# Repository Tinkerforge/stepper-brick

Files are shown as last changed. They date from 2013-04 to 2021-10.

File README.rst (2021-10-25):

Stepper Brick
=============

This repository contains the firmware source code and the hardware design
files. The documentation generator configs can be found at
https://github.com/Tinkerforge/generators

Repository Content
------------------

software/:
 * examples/: Examples for all supported languages
 * build/: Compiled files
 * src/: Source code of firmware
 * Makefile: Makefile to build project

hardware/:
 * Contains KiCad project files and additionally schematics as PDF

datasheets/:
 * Contains datasheets for sensors and complex ICs that are used

Hardware
--------

The hardware is designed with the open source EDA Suite KiCad
(http://www.kicad.org). Before you are able to open the files,
you have to install the Tinkerforge kicad-libraries
(https://github.com/Tinkerforge/kicad-libraries). You can either clone
them directly in hardware/ or clone them in a separate folder and
symlink them into hardware/
(ln -s kicad_path/kicad-libraries project_path/hardware). After that you
can open the .pro file in hardware/ with KiCad and from there view and
modify the schematics and the PCB layout.

Software
--------

If you want to do your own Brick/Bricklet firmware development we highly
recommend that you use our build environment setup script and read the
tutorial (https://www.tinkerforge.com/en/doc/Tutorials/Tutorial_Build_Environment/Tutorial.html).

To compile the C code we recommend you to install the newest GNU Arm Embedded
Toolchain (https://launchpad.net/gcc-arm-embedded/+download).
You also need to install bricklib (https://github.com/Tinkerforge/bricklib).

You can either clone it directly in software/src/ or clone it in a
separate folder and symlink it into software/src/
(ln -s bricklib_path/bricklib project_path/software/src/). Finally make sure to
have CMake installed (http://www.cmake.org/cmake/resources/software.html).

After that you can build the firmware by invoking make in software/.
The firmware (.bin) can then be found in software/build/ and uploaded
with brickv (click button "Flashing" on start screen).

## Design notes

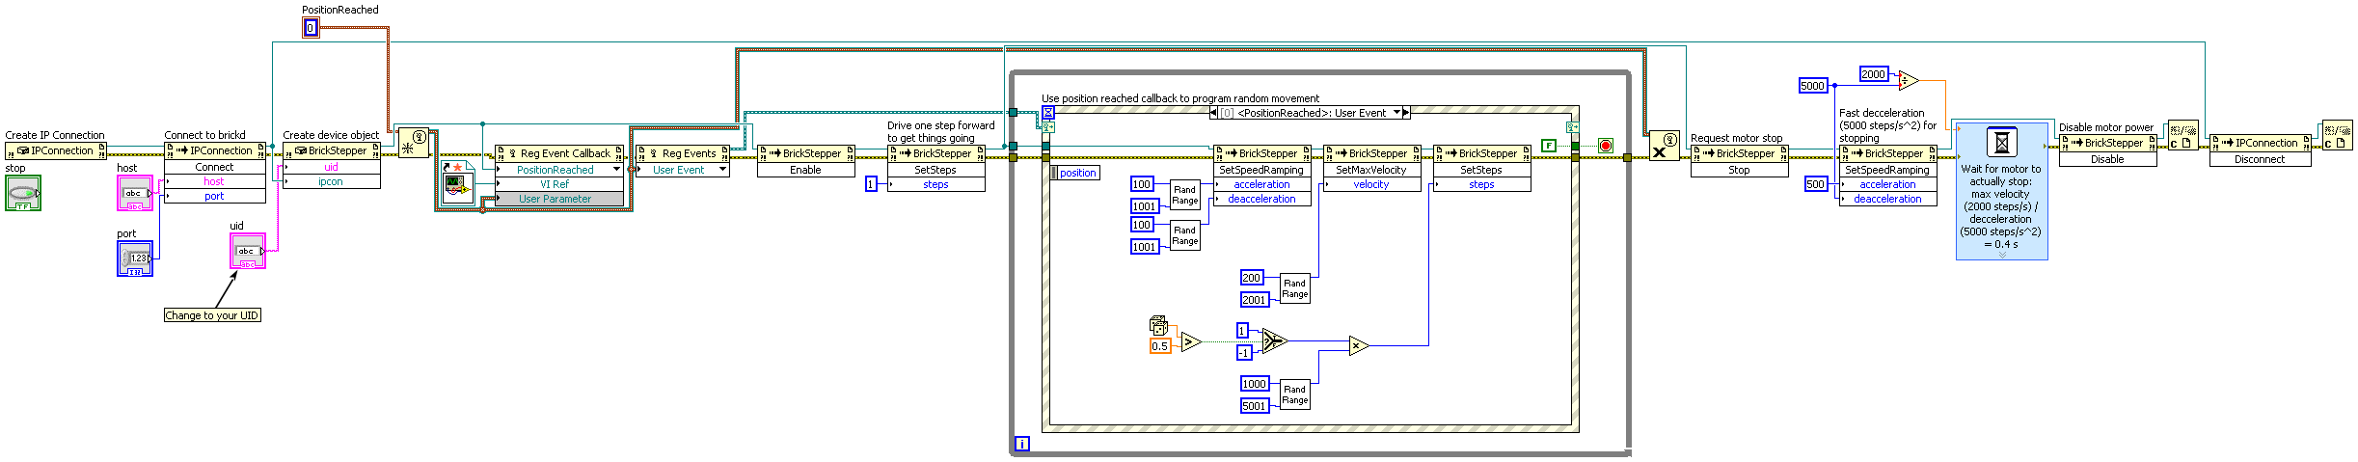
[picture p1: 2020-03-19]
software/examples/labview/Example Callback.vi.png

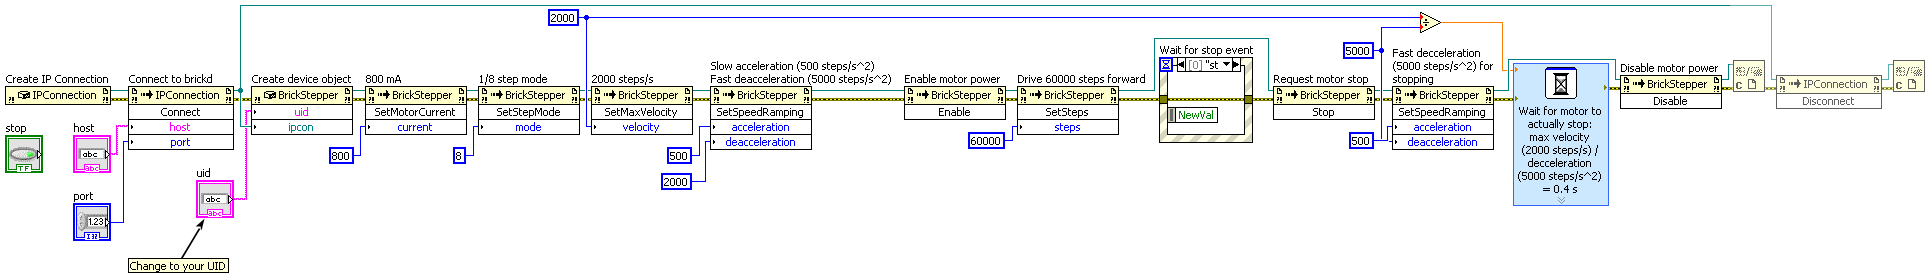
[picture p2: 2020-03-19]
software/examples/labview/Example Configuration.vi.png

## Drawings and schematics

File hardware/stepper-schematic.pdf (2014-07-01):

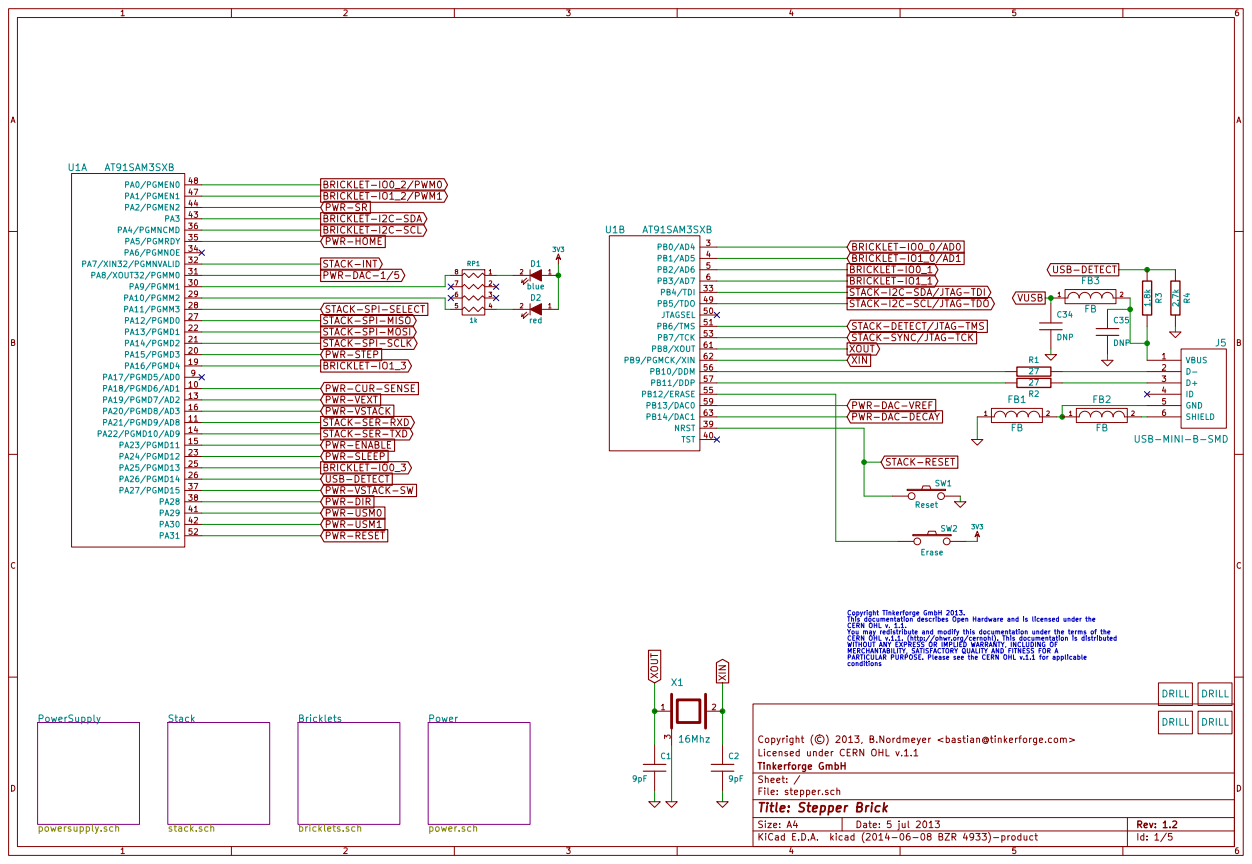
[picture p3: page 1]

BRICKLET-IO0_2/PWM0 Bricklets bricklets.sch
BRICKLET-IO1_2/PWM1
PWR-SR
BRICKLET-I2C-SDA
BRICKLET-I2C-SCL
1k PWR-HOME
3V3 BRICKLET-IO1_3
STACK-INT
conditions PWR-DAC-1/5
STACK-SER-RXD
STACK-SER-TXD
PWR-ENABLE
PWR-SLEEP
BRICKLET-IO0_3
PWR-VSTACK-SW
PWR-USM0 PWR-DIR

BRICKLET-IO0_0/AD0
BRICKLET-IO1_0/AD1
BRICKLET-IO0_1
BRICKLET-IO1_1
STACK-I2C-SDA/JTAG-TDI
STACK-I2C-SCL/JTAG-TDO

STACK-DETECT/JTAG-TMS
STACK-SYNC/JTAG-TCK
XOUT
XIN

Copyright Tinkerforge GmbH 2013. This documentation describes Open Hardware and is licensed under the CERN OHL v. 1.1. You may redistribute and modify this documentation under the terms of the CERN OHL v.1.1. (http://ohwr.org/cernohl). This documentation is distributed WITHOUT ANY EXPRESS OR IMPLIED WARRANTY, INCLUDING OF MERCHANTABILITY, SATISFACTORY QUALITY AND FITNESS FOR A

PARTICULAR PURPOSE. Please see the CERN OHL v.1.1 for applicable

Licensed under CERN OHL v.1.1 Copyright (©) 2013, B.Nordmeyer <bastian@tinkerforge.com>

File: stepper.sch Sheet: / Tinkerforge GmbH

Id: 1/5 Title: Stepper Brick

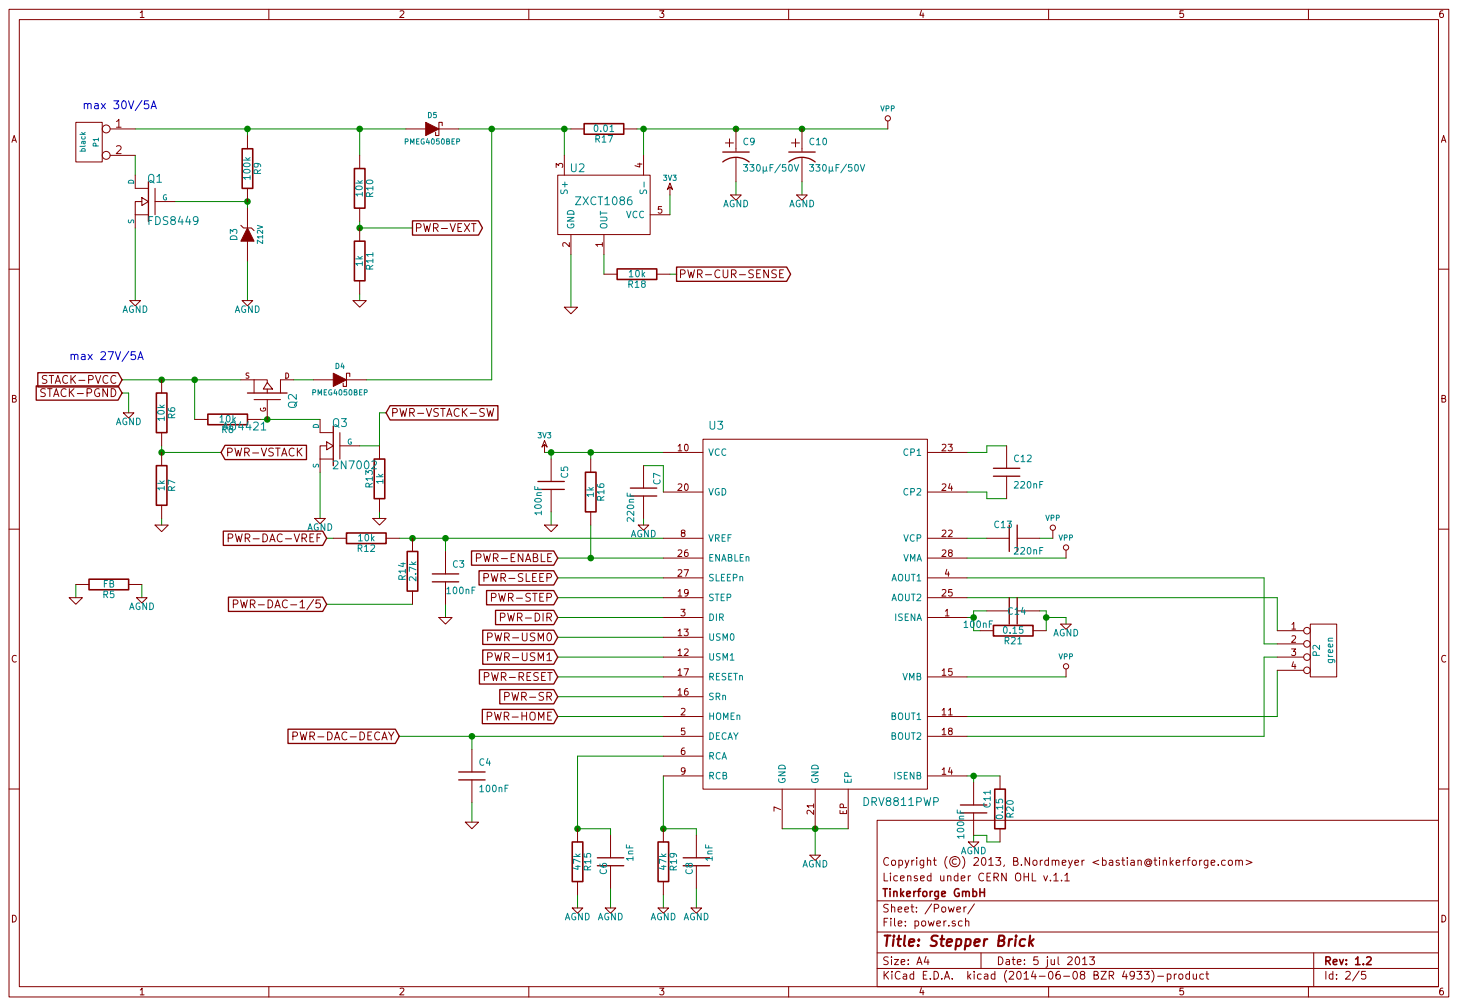
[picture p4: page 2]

7 VREF 8 RCB 9 VCC 10 VGD 20 BOUT1 11 GND 21 USM1 12 VCP 22 USM0 13 CP1 23

Licensed under CERN OHL v.1.1 Copyright (©) 2013, B.Nordmeyer <bastian@tinkerforge.com>

File: power.sch Sheet: /Power/ Tinkerforge GmbH

Id: 2/5 Title: Stepper Brick

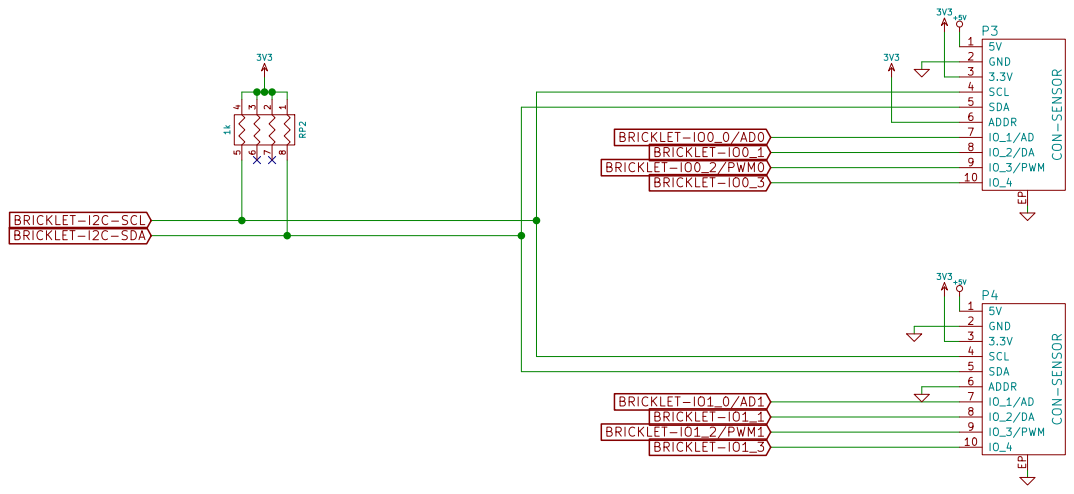
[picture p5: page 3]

File: bricklets.sch Sheet: /Bricklets/ Tinkerforge GmbH

Id: 3/5 Title: Stepper Brick

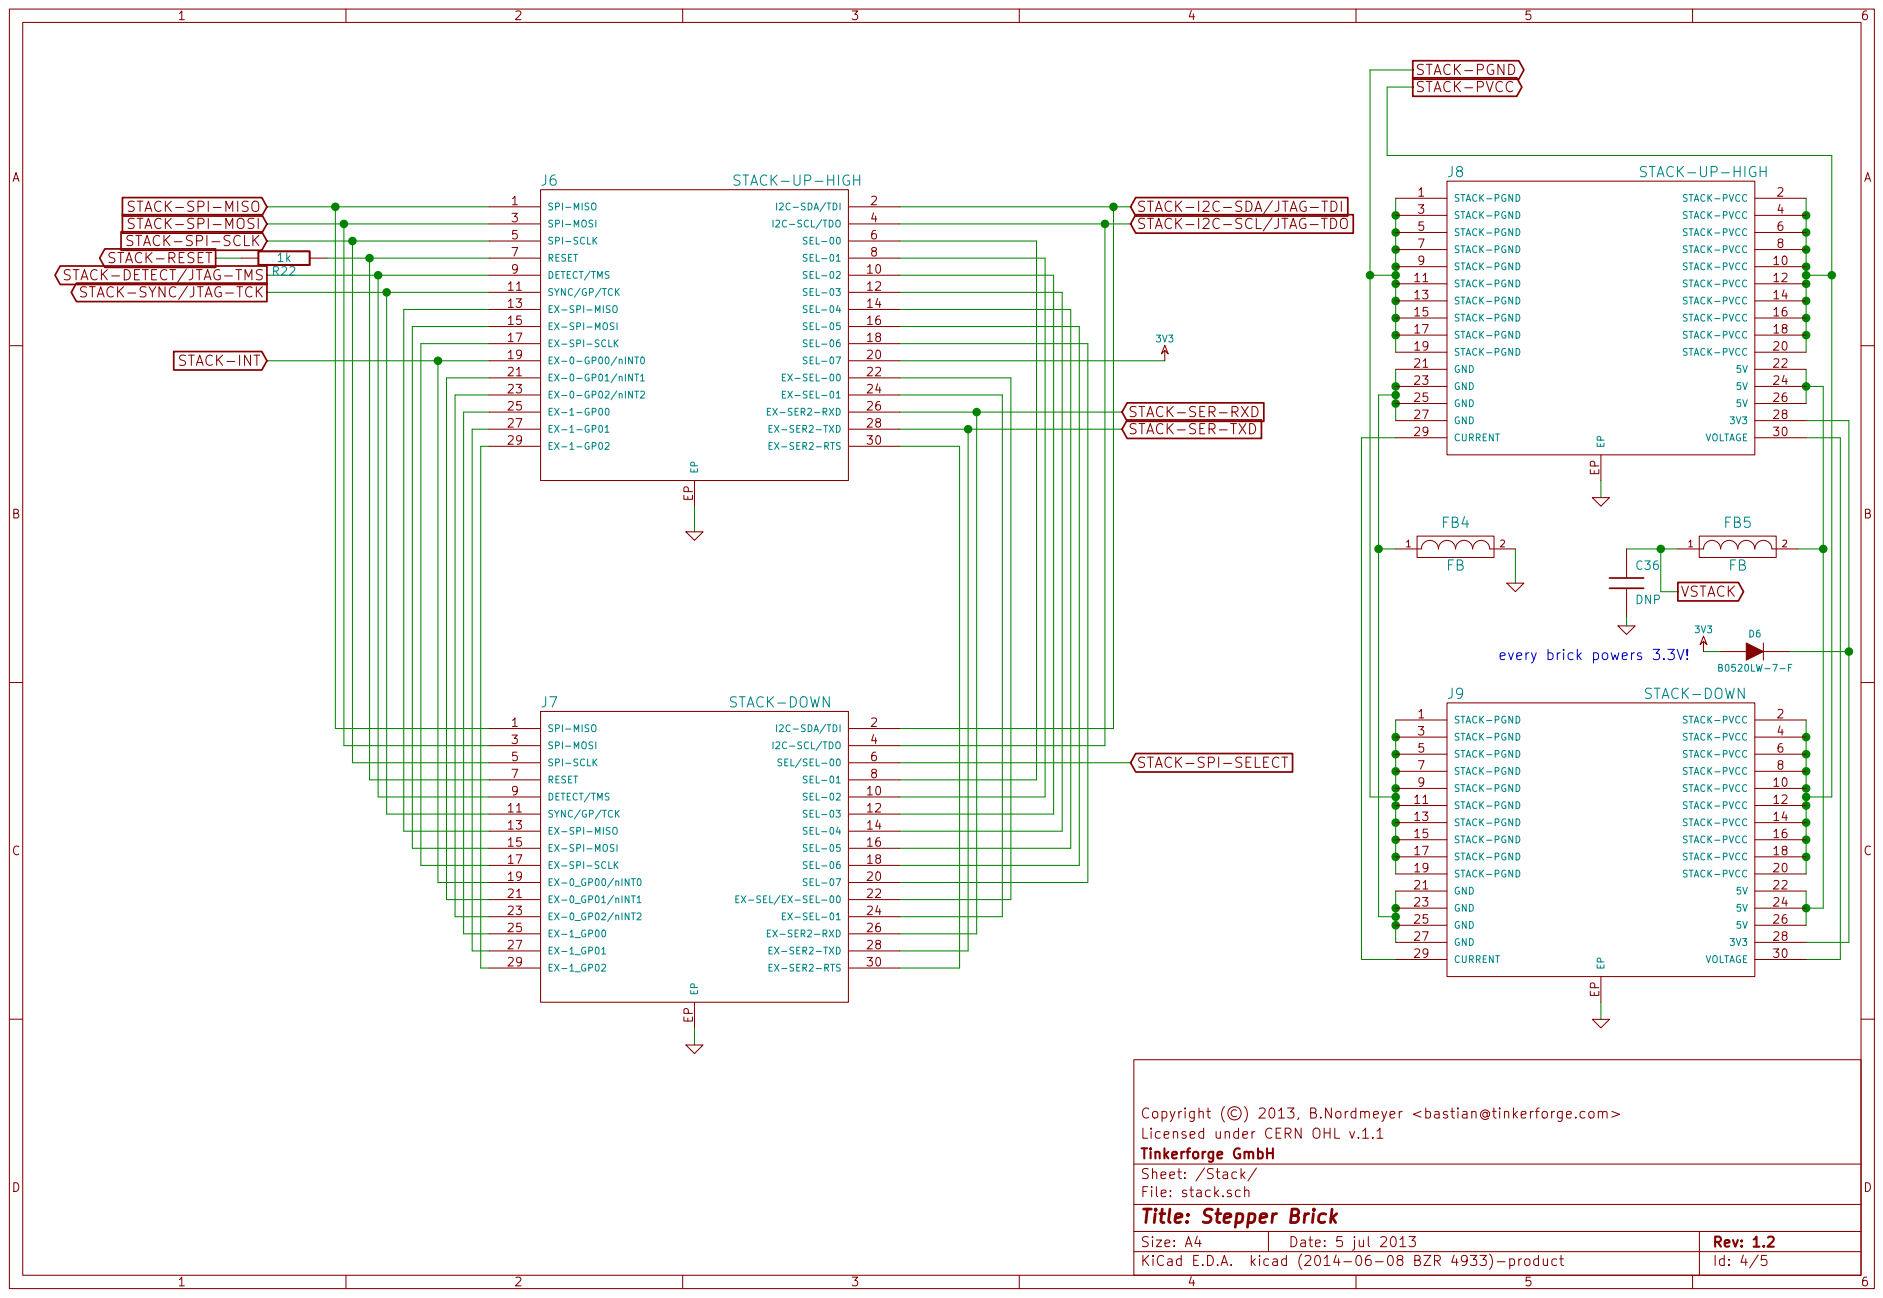
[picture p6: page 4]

STACK-SPI-MISO
STACK-SPI-MOSI
STACK-SPI-SCLK
STACK-RESET
STACK-DETECT/JTAG-TMS
STACK-SYNC/JTAG-TCK

STACK-I2C-SDA/JTAG-TDI
STACK-I2C-SCL/JTAG-TDO

Licensed under CERN OHL v.1.1 Copyright (©) 2013, B.Nordmeyer <bastian@tinkerforge.com>

File: stack.sch Sheet: /Stack/ Tinkerforge GmbH

Id: 4/5 Title: Stepper Brick

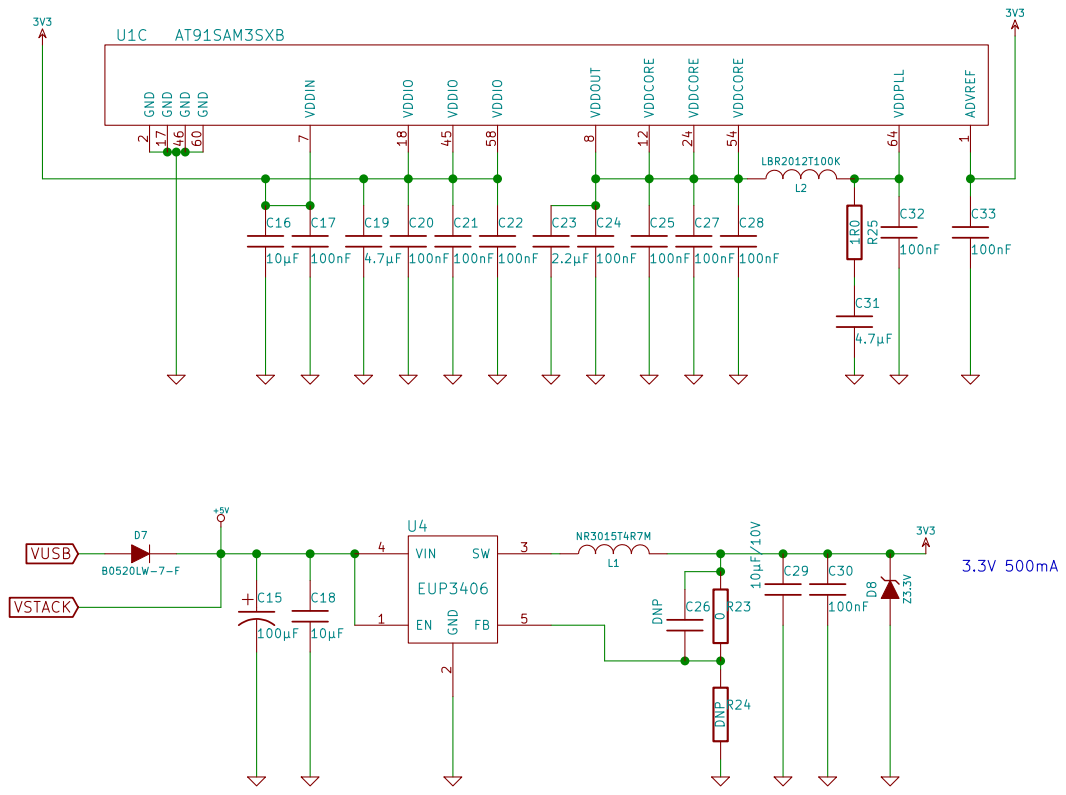
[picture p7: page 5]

8 GND 60 VDDCORE 12 VDDCORE 24 VDDCORE 54 VDDPLL 64 VDDIO 45 GND 46 GND 17 VDDIO 18 VDDIO 58

Licensed under CERN OHL v.1.1 Copyright (©) 2013, B.Nordmeyer <bastian@tinkerforge.com>

Tinkerforge GmbH
Sheet: /PowerSupply/
File: powersupply.sch
Id: 5/5 Title: Stepper Brick

D Date: 5 jul 2013

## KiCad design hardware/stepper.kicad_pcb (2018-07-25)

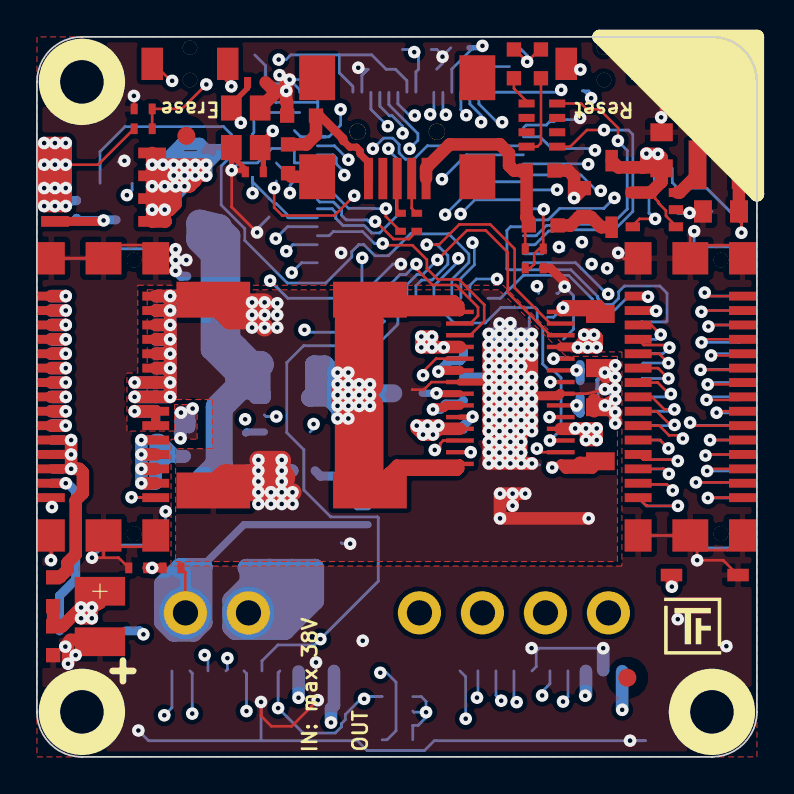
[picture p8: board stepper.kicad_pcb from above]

Board: 4 copper layers, 40.0 x 40.0 mm, 107 parts (0 on the bottom side), 109 nets.

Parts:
C1, C2: 9pF; C0402
C3, C4, C5, C11, C14, C17, C20, C21, C22, C24, C25, C27, C28, C30, C32, C33: 100nF; C0402
C6, C8: 1nF; C0402
C7, C12, C13: 220nF; C0603
C9, C10: 330µF/50V; ELKO_103
C15: 100µF; 3528-21
C16, C18: 10µF; C0805
C19, C31: 4.7µF; C0603
C23: 2.2µF; C0603
C26: DNP; C0402
C29: 10µF/10V; C0805
C34, C35, C36: DNP; C0603
D1: blue; D0603
D2: red; D0603
D3: Z12V; SOD-123
D4, D5: PMEG4050BEP; SOD-128
D6, D7: B0520LW-7-F; SOD-123
D8: Z3.3V; SOD-123
FB1, FB2, FB3, FB4, FB5: FB; C0603
Fiducial_Mark: VAL**; Fiducial_Mark
Fiducial_Mark#2, Fiducial_Mark#3, Fiducial_Mark#4: VAL**; Fiducial_Mark
J1, J2, J3, J4: DRILL; DRILL_NP
J5: USB-MINI-B-SMD
J6, J8: STACK-UP-HIGH; BTB08-ACS-TOP
J7, J9: STACK-DOWN; BTB08-ACS-BTM
L1: NR3015T4R7M; NR3030
L2: LBR2012T100K; C0805
P1: black; OQ_2P
P2: green; OQ_4P
P3, P4: CON-SENSOR
Q1: FDS8449; SOIC-8-MOSFET
Q2: AO4421; SOIC-8-MOSFET
Q3: 2N7002; SOT23GDS
R1, R2: 27; R0402
R3: 1.8k; R0402
R4, R14: 2.7k; R0402
R5: FB; C0603
R6, R10, R12, R18: 10k; R0402
R7, R11, R13, R16, R22: 1k; R0402
R8: 10k; 0402
R9: 100k; R0402
R15, R19: 47k; R0402
R17: 0.01; R1206
R20, R21: 0.15; R1206
R23: 0; R0603
R24: DNP; R0603
R25: 1R0; R0402
RP1, RP2: 1k; 4X0603
SW1: Reset; TACT-SWITCH
SW2: Erase; TACT-SWITCH
U1: AT91SAM3SXB; LQFP64
U2: ZXCT1086; SOT23-5
U3: DRV8811PWP; HTSSOP28
U4: EUP3406; SOT23-5
VAL: WEEE_7mm
VAL#2: CE_5mm
X1: 16Mhz; CRYSTAL_3225

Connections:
3V3: C5.2, C16.1, C17.1, C19.1, C20.1, C21.1, C22.1, C26.1, C29.1, C30.1, C33.1, D1.1, D2.1, D6.1, D8.2, J6.20, L1.2, P3.3, P3.6, P4.3, R16.1, R23.1, RP2.1, RP2.2, RP2.3, RP2.4, SW2.2, U1.1, U1.7, U1.18, U1.45, U1.58, U2.5, U3.10
BRICKLET-I2C-SCL: P3.4, P4.4, RP2.5, U1.36
BRICKLET-I2C-SDA: P3.5, P4.5, RP2.8, U1.43
BRICKLET-IO0_0/AD0: P3.7, U1.3
BRICKLET-IO0_1: P3.8, U1.5
BRICKLET-IO0_2/PWM0: P3.9, U1.48
BRICKLET-IO0_3: P3.10, U1.25
BRICKLET-IO1_0/AD1: P4.7, U1.4
BRICKLET-IO1_1: P4.8, U1.6
BRICKLET-IO1_2/PWM1: P4.9, U1.47
BRICKLET-IO1_3: P4.10, U1.19
GND: C1.2, C2.2, C3.2, C4.2, C5.1, C15.2, C16.2, C17.2, C18.2, C19.2, C20.2, C21.2, C22.2, C23.2, C24.2, C25.2, C27.2, C28.2, C29.2, C30.2, C31.2, C32.2, C33.2, C34.2, C35.2, C36.2, D8.1, FB1.1, FB4.2, J6.EP, J7.EP, J8.EP, J9.EP, P3.2, P3.EP, P4.2, P4.6, P4.EP, R4.1, R5.2, R7.2, R11.2, R13.1, R24.2, SW1.2, U1.2, U1.17, U1.46, U1.60, U2.2, U4.2, X1.3
unnamed: C3.1, R12.1, R14.2, U3.8
unnamed: C6.1, R15.1, U3.6
unnamed: C7.2, U3.20
unnamed: C8.1, R19.1, U3.9
unnamed: C11.2, R20.1, U3.14
unnamed: C12.1, U3.23
unnamed: C12.2, U3.24
unnamed: C13.2, U3.22
unnamed: C14.1, R21.2, U3.1
unnamed: C23.1, C24.1, C25.1, C27.1, C28.1, L2.1, U1.8, U1.12, U1.24, U1.54
unnamed: C26.2, R23.2, R24.1, U4.5
unnamed: C31.1, R25.1
unnamed: C32.1, L2.2, R25.2, U1.64
unnamed: C35.1, FB3.2, J5.1, R3.1
unnamed: D1.2, RP1.1
unnamed: D2.2, RP1.4
unnamed: D3.2, Q1.G, R9.2
unnamed: D4.1, Q2.D
unnamed: D4.2, D5.2, R17.2, U2.3
unnamed: D5.1, P1.1, R9.1, R10.1
unnamed: D6.2, J8.28, J9.28
unnamed: FB1.2, FB2.1, J5.5
unnamed: FB2.2, J5.6
unnamed: FB4.1, J8.21, J8.23, J8.25, J8.27, J9.21, J9.23, J9.25, J9.27
unnamed: FB5.2, J8.22, J8.24, J8.26, J9.22, J9.24, J9.26
unnamed: J5.2, R1.1
unnamed: J5.3, R2.1
unnamed: J6.6, J7.8
unnamed: J6.7, J7.7, R22.1
unnamed: J6.8, J7.10
unnamed: J6.10, J7.12
unnamed: J6.12, J7.14
unnamed: J6.13, J7.13
unnamed: J6.14, J7.16
unnamed: J6.15, J7.15
unnamed: J6.16, J7.18
unnamed: J6.17, J7.17
unnamed: J6.18, J7.20
unnamed: J6.21, J7.21
unnamed: J6.22, J7.22
unnamed: J6.23, J7.23
unnamed: J6.24, J7.24
unnamed: J6.25, J7.25
unnamed: J6.27, J7.27
unnamed: J6.29, J7.29
unnamed: J6.30, J7.30
unnamed: J8.29, J9.29
unnamed: J8.30, J9.30
unnamed: L1.1, U4.3
unnamed: P1.2, Q1.D
unnamed: P2.1, U3.25
unnamed: P2.2, U3.4
unnamed: P2.3, U3.18
unnamed: P2.4, U3.11
unnamed: Q2.G, Q3.D, R8.1
unnamed: R1.2, U1.56
unnamed: R2.2, U1.57
unnamed: R18.2, U2.1
unnamed: RP1.5, U1.29
unnamed: RP1.8, U1.30
unnamed: SW2.1, U1.55
PWR-CUR-SENSE: R18.1, U1.10
PWR-DAC-1/5: R14.1, U1.31
PWR-DAC-DECAY: C4.1, U1.63, U3.5
PWR-DAC-VREF: R12.2, U1.59
PWR-DIR: U1.38, U3.3
PWR-ENABLE: R16.2, U1.15, U3.26
PWR-HOME: U1.35, U3.2
PWR-RESET: U1.52, U3.17
PWR-SLEEP: U1.23, U3.27
PWR-SR: U1.44, U3.16
PWR-STEP: U1.20, U3.19
PWR-USM0: U1.41, U3.13
PWR-USM1: U1.42, U3.12
PWR-VEXT: R10.2, R11.1, U1.13
PWR-VSTACK: R6.2, R7.1, U1.16
PWR-VSTACK-SW: Q3.G, R13.2, U1.37
STACK-DETECT/JTAG-TMS: J6.9, J7.9, U1.51
STACK-I2C-SCL/JTAG-TDO: J6.4, J7.4, U1.49
STACK-I2C-SDA/JTAG-TDI: J6.2, J7.2, U1.33
STACK-INT: J6.19, J7.19, U1.32
STACK-PGND: C6.2, C7.1, C8.2, C9.2, C10.2, C11.1, C14.2, D3.1, J8.1, J8.3, J8.5, J8.7, J8.9, J8.11, J8.13, J8.15, J8.17, J8.19, J9.1, J9.3, J9.5, J9.7, J9.9, J9.11, J9.13, J9.15, J9.17, J9.19, Q1.S, Q3.S, R5.1, R15.2, R19.2, R20.2, R21.1, U3.7, U3.21, U3.EP
STACK-PVCC: J8.2, J8.4, J8.6, J8.8, J8.10, J8.12, J8.14, J8.16, J8.18, J8.20, J9.2, J9.4, J9.6, J9.8, J9.10, J9.12, J9.14, J9.16, J9.18, J9.20, Q2.S, R6.1, R8.2
STACK-RESET: R22.2, SW1.1, U1.39
STACK-SER-RXD: J6.26, J7.26, U1.11
STACK-SER-TXD: J6.28, J7.28, U1.14
STACK-SPI-MISO: J6.1, J7.1, U1.27
STACK-SPI-MOSI: J6.3, J7.3, U1.22
STACK-SPI-SCLK: J6.5, J7.5, U1.21
STACK-SPI-SELECT: J7.6, U1.28
STACK-SYNC/JTAG-TCK: J6.11, J7.11, U1.53
USB-DETECT: R3.2, R4.2, U1.26
VPP: C9.1, C10.1, C13.1, R17.1, U2.4, U3.15, U3.28
VSTACK: C15.1, C18.1, C36.1, D7.2, FB5.1, P3.1, P4.1, U4.1, U4.4
VUSB: C34.1, D7.1, FB3.1
XIN: C2.1, U1.62, X1.2
XOUT: C1.1, U1.61, X1.1

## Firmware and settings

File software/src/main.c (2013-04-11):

/* stepper-brick
 * Copyright (C) 2010-2013 Olaf Lüke <olaf@tinkerforge.com>
 *
 * main.c: Stepper Brick startup code
 *
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
 * You should have received a copy of the GNU Lesser General Public
 * License along with this library; if not, write to the
 * Free Software Foundation, Inc., 59 Temple Place - Suite 330,
 * Boston, MA 02111-1307, USA.
 */

#include <stdbool.h>
#include <stdint.h>
#include <stdio.h>
#include <stdlib.h>

#include "bricklib/free_rtos/include/FreeRTOS.h"
#include "bricklib/free_rtos/include/task.h"

#include "bricklib/com/i2c/i2c_pca9549/i2c_pca9549.h"
#include "bricklib/com/spi/spi_stack/spi_stack_master.h"
#include "bricklib/com/spi/spi_stack/spi_stack_slave.h"
#include "bricklib/com/spi/spi_stack/spi_stack_common.h"
#include "bricklib/com/i2c/i2c_eeprom/i2c_eeprom_master.h"
#include "bricklib/com/i2c/i2c_eeprom/i2c_eeprom_slave.h"
#include "bricklib/com/usb/usb.h"
#include "bricklib/logging/logging.h"
#include "bricklib/bricklet/bricklet_init.h"
#include "bricklib/drivers/uid/uid.h"
#include "bricklib/drivers/wdt/wdt.h"
#include "bricklib/drivers/pio/pio.h"
#include "bricklib/utility/init.h"
#include "bricklib/utility/profiling.h"
#include "bricklib/utility/led.h"
#include "bricklib/logging/logging.h"

#include "config.h"
#include "communication.h"
#include "stepper.h"

uint8_t brick_hardware_version[3];
extern bool usb_first_connection;

void vApplicationStackOverflowHook(xTaskHandle *pxTask, signed char *pcTaskName) {
	logf("Stack Overflow\n\r");
	while(true);
}

int main() {
	brick_hardware_version[0] = BRICK_HARDWARE_VERSION_MAJOR;
	brick_hardware_version[1] = BRICK_HARDWARE_VERSION_MINOR;
	brick_hardware_version[2] = BRICK_HARDWARE_VERSION_REVISION;

	brick_init();
	wdt_restart();

    if(usb_is_connected()) {
    	logi("Configure as USB device\n\r");
    	usb_init();
    	wdt_restart();

    	xTaskCreate(usb_message_loop,
    				(signed char *)"usb_ml",
    				1000,
    				NULL,
    				1,
    				(xTaskHandle *)NULL);
    } else {
    	logi("Configure as Stack Participant (SPI)\n\r");
    	usb_first_connection = false;
        spi_stack_slave_init();
    	wdt_restart();

    	xTaskCreate(spi_stack_slave_message_loop,
    			    (signed char *)"spi_ml",
    			    2500,
    			    NULL,
    			    1,
    			    (xTaskHandle *)NULL);
    }

	stepper_init();
    wdt_restart();

	brick_init_start_tick_task();
    wdt_restart();

	vTaskStartScheduler();
}

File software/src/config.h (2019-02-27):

/* stepper-brick
 * Copyright (C) 2010-2012 Olaf Lüke <olaf@tinkerforge.com>
 *
 * config.h: Stepper-Brick specific configuration
 *
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
 * You should have received a copy of the GNU Lesser General Public
 * License along with this library; if not, write to the
 * Free Software Foundation, Inc., 59 Temple Place - Suite 330,
 * Boston, MA 02111-1307, USA.
 */

#ifndef CONFIG_H
#define CONFIG_H

#include "communication.h"
#include "bricklib/drivers/board/sam3s/SAM3S.h"
#include "stepper.h"

#define BRICK_FIRMWARE_VERSION_MAJOR 2
#define BRICK_FIRMWARE_VERSION_MINOR 3
#define BRICK_FIRMWARE_VERSION_REVISION 10

#define BRICK_HARDWARE_VERSION_MAJOR 1
#define BRICK_HARDWARE_VERSION_MINOR 1
#define BRICK_HARDWARE_VERSION_REVISION 0

#define BRICK_DEVICE_IDENTIFIER 15

// ************** DEBUG SETTINGS **************
#define DEBUG_SPI_STACK 1
#define DEBUG_I2C_EEPROM 0
#define DEBUG_STARTUP 1
#define DEBUG_BRICKLET 1
#define DEBUG_STEPPER 1
//#define PROFILING
//#define PROFILING_TIME 100 // After how many seconds profiling is printed

#define DISABLE_JTAG_ON_STARTUP
//#define LOGGING_SERIAL
//#define LOGGING_LEVEL LOGGING_DEBUG
#define LOGGING_LEVEL LOGGING_NONE


// ************** BRICK SETTINGS **************

// Frequencies
#define BOARD_MCK      64000000 // Frequency of brick
#define BOARD_MAINOSC  16000000 // Frequency of oscillator
#define BOARD_ADC_FREQ 16000000 // Frequency of ADC
#define BOARD_OSC_EXTERNAL      // Use external oscillator

#define BRICK_HAS_CO_MCU_SUPPORT

// UART for console output (printf)
#define PIN_CONSOLE_RXD  {1 << 21, PIOA, ID_PIOA, PIO_PERIPH_A, PIO_DEFAULT}
#define PIN_CONSOLE_TXD  {1 << 22, PIOA, ID_PIOA, PIO_PERIPH_A, PIO_DEFAULT}

#define CONSOLE_BAUDRATE 115200
#define CONSOLE_USART    USART1
#define CONSOLE_ID       ID_USART1
#define CONSOLE_PINS     {PIN_CONSOLE_RXD, PIN_CONSOLE_TXD}

#define PINS_UART        {PIN_CONSOLE_RXD, PIN_CONSOLE_TXD}

// TWI
// TWI version
#define TWI_V3XX

// TWI stack definitions (for reading of eeproms from Bricks in stack)
#define TWI_STACK           TWI1
#define PIN_TWI_TWD_STACK   {1 << 4, PIOB, ID_PIOB, PIO_PERIPH_A, PIO_DEFAULT}
#define PIN_TWI_TWCK_STACK  {1 << 5, PIOB, ID_PIOB, PIO_PERIPH_A, PIO_DEFAULT}
#define PINS_TWI_STACK      PIN_TWI_TWD_STACK, PIN_TWI_TWCK_STACK

// TWI bricklet definitions (for bricklets, spi select and brick specific
//                           functions)
#define TWI_BRICKLET           TWI0
#define PIN_TWI_TWD_BRICKLET   {1 << 3, PIOA, ID_PIOA, PIO_PERIPH_A, PIO_DEFAULT}
#define PIN_TWI_TWCK_BRICKLET  {1 << 4, PIOA, ID_PIOA, PIO_PERIPH_A, PIO_DEFAULT}
#define PINS_TWI_BRICKLET      PIN_TWI_TWD_BRICKLET, PIN_TWI_TWCK_BRICKLET

// USB
// USB VBUS monitoring pin for USB plug and play
#define PIN_USB_DETECT  {1 << 26, PIOA, ID_PIOA, PIO_INPUT, PIO_DEFAULT}
// USB product descriptor (name of brick)
#define PRODUCT_DESCRIPTOR { \
	USBStringDescriptor_LENGTH(13), \
    USBGenericDescriptor_STRING, \
    USBStringDescriptor_UNICODE('S'), \
    USBStringDescriptor_UNICODE('t'), \
    USBStringDescriptor_UNICODE('e'), \
    USBStringDescriptor_UNICODE('p'), \
    USBStringDescriptor_UNICODE('p'), \
    USBStringDescriptor_UNICODE('e'), \
    USBStringDescriptor_UNICODE('r'), \
    USBStringDescriptor_UNICODE(' '), \
    USBStringDescriptor_UNICODE('B'), \
    USBStringDescriptor_UNICODE('r'), \
    USBStringDescriptor_UNICODE('i'), \
    USBStringDescriptor_UNICODE('c'), \
    USBStringDescriptor_UNICODE('k') \
}


// SPI
#define PIN_SPI_MISO        {1 << 12, PIOA, ID_PIOA, PIO_PERIPH_A, PIO_DEFAULT}
#define PIN_SPI_MOSI        {1 << 13, PIOA, ID_PIOA, PIO_PERIPH_A, PIO_DEFAULT}
#define PIN_SPI_SPCK        {1 << 14, PIOA, ID_PIOA, PIO_PERIPH_A, PIO_DEFAULT}

#define PINS_SPI            PIN_SPI_MISO, PIN_SPI_MOSI, PIN_SPI_SPCK

#define PIN_SPI_SELECT_SLAVE  {1 << 11, PIOA, ID_PIOA, PIO_PERIPH_A, PIO_DEFAULT}

// LED
#define PIN_LED_STD_BLUE    {1 << 9, PIOA, ID_PIOA, PIO_OUTPUT_1, PIO_DEFAULT}
#define PIN_LED_STD_RED     {1 << 10, PIOA, ID_PIOA, PIO_OUTPUT_1, PIO_DEFAULT}
#define PINS_STD_LED        PIN_LED_STD_BLUE, PIN_LED_STD_RED
#define PINS_LED            PINS_STD_LED

#define LED_STD_BLUE        0
#define LED_STD_RED         1


// Brick Detect
// Set low by master
// TODO: Change name
#define PIN_DETECT        {1 << 6, PIOB, ID_PIOB, PIO_OUTPUT_0, PIO_DEFAULT}



// ************** INTERRUPT PRIORITIES ***********
#define PRIORITY_EEPROM_MASTER_TWI0  1
#define PRIORITY_EEPROM_SLAVE_TWI1   1
#define PRIORITY_STACK_SLAVE_SPI     5
#define PRIORITY_PROFILING_TC0       0
#define PRIORITY_STEPPER_TC0         6

// ************** BRICKLET SETTINGS **************

// Number of bricklet ports
#define BRICKLET_NUM 2

// BRICKLET A
#define BRICKLET_A_ADDRESS 84
#define BRICKLET_A_ADC_CHANNEL 4
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

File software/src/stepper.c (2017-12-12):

/* stepper-brick
 * Copyright (C) 2010-2012 Olaf Lüke <olaf@tinkerforge.com>
 *
 * stepper.c: Implementation of Stepper-Brick specific functions
 *
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
 * You should have received a copy of the GNU Lesser General Public
 * License along with this library; if not, write to the
 * Free Software Foundation, Inc., 59 Temple Place - Suite 330,
 * Boston, MA 02111-1307, USA.
 */

#include "stepper.h"

#include "config.h"
#include "communication.h"

#include "bricklib/com/com.h"
#include "bricklib/com/com_common.h"
#include "bricklib/logging/logging.h"
#include "bricklib/bricklet/bricklet_init.h"
#include "bricklib/drivers/dacc/dacc.h"
#include "bricklib/drivers/adc/adc.h"
#include "bricklib/drivers/tc/tc.h"
#include "bricklib/drivers/pio/pio.h"
#include "bricklib/drivers/usart/usart.h"
#include "bricklib/drivers/pwmc/pwmc.h"
#include "bricklib/drivers/usb/USBD_HAL.h"
#include "bricklib/utility/util_definitions.h"
#include "bricklib/utility/led.h"
#include "bricklib/utility/init.h"
#include <stdio.h>

Pin pin_enable =  PIN_ENABLE;
Pin pin_sleep = PIN_SLEEP;
Pin pin_step = PIN_STEP;
Pin pin_direction = PIN_DIRECTION;
Pin pin_usm[2] = {PIN_USM0, PIN_USM1};
Pin pin_reset = PIN_RESET;
Pin pin_sync_rect = PIN_SYNC_RECT;
Pin pin_home = PIN_HOME;
Pin pin_vref = PIN_VREF;
Pin pin_decay = PIN_DECAY;
Pin pin_voltage_switch = VOLTAGE_STACK_SWITCH_PIN;

uint32_t stepper_velocity_goal = STEPPER_VELOCITY_DEFAULT;
uint32_t stepper_velocity = 0;
uint16_t stepper_acceleration = STEPPER_ACCELERATION_DEFAULT;
uint16_t stepper_acceleration_sqrt = STEPPER_ACCELERATION_SQRT_DEFAULT;
uint16_t stepper_deceleration = STEPPER_DECELERATION_DEFAUL;
uint16_t stepper_minimum_voltage = STEPPER_MINIMUM_VOLTAGE_DEFAULT;
uint16_t stepper_decay = 0;

int32_t stepper_position = 0;
int32_t stepper_target_position = 0;
int32_t stepper_steps = 0;
uint16_t stepper_output_current = 0;
int8_t stepper_state = STEPPER_STATE_OFF;
int8_t stepper_speedramp_state = STEPPER_SPEEDRAMP_STATE_STOP;
int8_t stepper_direction = STEPPER_DIRECTION_FORWARD;

int32_t stepper_step_counter = 0;
int32_t stepper_acceleration_counter = 0;
uint32_t stepper_acceleration_steps = 0;
int32_t stepper_deceleration_steps = 0;
int32_t stepper_delay = 0;
int32_t stepper_last_delay = 0;
int32_t stepper_delay_rest = 0;
int32_t stepper_deceleration_start = 0;
uint32_t stepper_tick_counter = 0;
uint32_t stepper_tick_calc_counter = 0;

uint32_t stepper_time_base = 1;
uint32_t stepper_time_base_counter = 1;
uint32_t stepper_all_data_period = 0;
uint32_t stepper_all_data_period_counter = 0;

bool stepper_running = false;
bool stepper_position_reached = false;

uint32_t stepper_current_sum = 0;
uint32_t stepper_current = 0;

bool stepper_sync_rect = false;

uint8_t stepper_api_state = STEPPER_API_STATE_STOP;
uint8_t stepper_api_prev_state = STEPPER_API_STATE_STOP;
bool stepper_api_state_send = false;

const uint32_t stepper_timer_frequency[] = {BOARD_MCK/2,
                                            BOARD_MCK/8,
                                            BOARD_MCK/32,
                                            BOARD_MCK/128,
                                            32768};
const uint32_t stepper_timer_velocity[]  = {BOARD_MCK/2   / MAX_TIMER_VALUE,
                                            BOARD_MCK/8   / MAX_TIMER_VALUE,
                                            BOARD_MCK/32  / MAX_TIMER_VALUE,
                                            BOARD_MCK/128 / MAX_TIMER_VALUE,
                                            32768         / MAX_TIMER_VALUE};

extern ComInfo com_info;
extern bool usb_first_connection;

void stepper_position_reached_signal(void) {
	PositionReachedSignal prs;
	com_make_default_header(&prs, com_info.uid, sizeof(PositionReachedSignal), FID_POSITION_REACHED);
	prs.position = stepper_position;

	send_blocking_with_timeout(&prs,
	                           sizeof(PositionReachedSignal),
	                           com_info.current);
}

void stepper_check_error_signals(void) {
	if(stepper_tick_counter % 1000 != 0 || stepper_state == STEPPER_STATE_OFF) {
		return;
	}

	const uint16_t external_voltage = stepper_get_external_voltage();
	const uint16_t stack_voltage    = stepper_get_stack_voltage();

	// Under Voltage if external voltage is below minimum voltage (regardless
	// of stack voltage), or if external voltage is zero and stack velotage is
	// below minimum voltage

	if((external_voltage > STEPPER_VOLTAGE_EPSILON &&
	    external_voltage < stepper_minimum_voltage) ||
	   (external_voltage < STEPPER_VOLTAGE_EPSILON &&
	    stack_voltage > STEPPER_VOLTAGE_EPSILON &&
	    stack_voltage < stepper_minimum_voltage)) {
		UnderVoltageSignal uvs;
		com_make_default_header(&uvs, com_info.uid, sizeof(UnderVoltageSignal), FID_UNDER_VOLTAGE);
		uvs.voltage = external_voltage < STEPPER_VOLTAGE_EPSILON ? stack_voltage : external_voltage;

		send_blocking_with_timeout(&uvs,
		                           sizeof(UnderVoltageSignal),
		                           com_info.current);
		led_on(LED_STD_RED);
	} else {
		led_off(LED_STD_RED);
	}
}

void stepper_make_drive_speedramp(const uint8_t state) {
	stepper_state = STEPPER_STATE_DRIVE;
	stepper_speedramp_state = state;

	if(state == STEPPER_SPEEDRAMP_STATE_STOP) {
		stepper_set_new_api_state(STEPPER_API_STATE_DECELERATION);
	} else if(state == STEPPER_SPEEDRAMP_STATE_BACKWARD ||
	          state == STEPPER_SPEEDRAMP_STATE_FORWARD) {
		stepper_set_new_api_state(STEPPER_API_STATE_ACCELERATION);
	}

	if(!stepper_is_currently_running()) {
		// call drive speedramp one time, to get it going
		// (i.e. make velocity != 0)
		stepper_drive_speedramp();
		TC0_IrqHandler();
	}
}
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

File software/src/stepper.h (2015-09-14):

/* stepper-brick
 * Copyright (C) 2010-2012 Olaf Lüke <olaf@tinkerforge.com>
 *
 * stepper.h: Implementation of Stepper-Brick specific functions
 *
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
 * You should have received a copy of the GNU Lesser General Public
 * License along with this library; if not, write to the
 * Free Software Foundation, Inc., 59 Temple Place - Suite 330,
 * Boston, MA 02111-1307, USA.
 */

#ifndef STEPPER_H
#define STEPPER_H

#include <stdint.h>
#include "config.h"
#include "bricklib/utility/util_definitions.h"

#define STEPPER_VELOCITY_DEFAULT           500
#define STEPPER_ACCELERATION_DEFAULT       1000
#define STEPPER_ACCELERATION_SQRT_DEFAULT  31 // sqrt(1000)
#define STEPPER_DECELERATION_DEFAUL        1000
#define STEPPER_MINIMUM_VOLTAGE_DEFAULT    8000
#define STEPPER_VOLTAGE_EPSILON            6000

#define VELOCITY_TO_DELAY(vel) ((2147483647/2)/(vel))
#define DELAY_TO_VELOCITY(del) ((2147483647/2)/(del))

#define MAX_TIMER_VALUE 0xFFFF

#define STEPPER_PWM_MAX_DUTY_CYCLE 128

#define STEPPER_TC_CHANNEL_NUM 0
#define STEPPER_TC_CHANNEL (TC0->TC_CHANNEL[STEPPER_TC_CHANNEL_NUM])
#define STEPPER_COUNTER STEPPER_TC_CHANNEL.TC_RC

#define SINGLE_SHOT_TC_CHANNEL_NUM 1
#define SINGLE_SHOT_TC_CHANNEL (TC0->TC_CHANNEL[SINGLE_SHOT_TC_CHANNEL_NUM])
#define SINGLE_SHOT_COUNTER SINGLE_SHOT_TC_CHANNEL.TC_RC

#define STEP_MODE_FULL       1
#define STEP_MODE_HALF       2
#define STEP_MODE_QUARTER    4
#define STEP_MODE_EIGTH      8

// (0.2*3300)
#define DECAY_MIN_VALUE      SCALE(660, VOLTAGE_MIN_DAC, VOLTAGE_MAX_DAC, \
                                        VOLTAGE_MIN_VALUE, VOLTAGE_MAX_VALUE)
// (0.61*3300)
#define DECAY_MAX_VALUE      SCALE(2013, VOLTAGE_MIN_DAC, VOLTAGE_MAX_DAC, \
                                         VOLTAGE_MIN_VALUE, VOLTAGE_MAX_VALUE)

#define DECAY_DEFAULT_VALUE  10000

#define STEPPER_STATE_OFF    1
#define STEPPER_STATE_STOP   2
#define STEPPER_STATE_DRIVE  3
#define STEPPER_STATE_STEPS  4
#define STEPPER_STATE_TARGET 5

// Define forward and backward same as for direction,
// this allows for easy comparisons
#define STEPPER_SPEEDRAMP_STATE_FORWARD        1
#define STEPPER_SPEEDRAMP_STATE_BACKWARD      -1
#define STEPPER_SPEEDRAMP_STATE_STOP           2
#define STEPPER_SPEEDRAMP_STATE_ACCELERATION   3
#define STEPPER_SPEEDRAMP_STATE_RUN            4
#define STEPPER_SPEEDRAMP_STATE_DECELERATION   5

#define STEPPER_DIRECTION_FORWARD   1
#define STEPPER_DIRECTION_BACKWARD -1

#define STEPPER_API_STATE_STOP 1
#define STEPPER_API_STATE_ACCELERATION 2
#define STEPPER_API_STATE_RUN 3
#define STEPPER_API_STATE_DECELERATION 4
#define STEPPER_API_STATE_DIR_CHANGE_FORWARD 5
#define STEPPER_API_STATE_DIR_CHANGE_BACKWARD 6

void new_connection(void);
void stepper_init(void);
void stepper_set_output_current(const uint16_t current);
void stepper_set_step_mode(const uint8_t mode);
uint8_t stepper_get_step_mode(void);
void stepper_set_decay(const uint16_t decay);
void stepper_enable(void);
void stepper_disable(void);
void stepper_update_tc_frequency(void);
uint16_t stepper_get_external_voltage(void);
uint16_t stepper_get_stack_voltage(void);
void tick_task(const uint8_t tick_type);
void stepper_set_direction(const int8_t direction);
void TC1_IrqHandler(void);
void stepper_position_reached_signal(void);
bool stepper_is_currently_running(void);
void stepper_set_next_timer(const uint32_t velocity);
void stepper_make_step(void);
void stepper_make_step_speedramp(const int32_t steps);
void stepper_step_speedramp(void);
void stepper_make_drive_speedramp(const uint8_t state);
void stepper_drive_speedramp(void);
void stepper_full_brake(void);
void stepper_check_error_signals(void);
uint16_t stepper_get_current(void);
void stepper_set_sync_rect(bool sr);
int32_t stepper_get_remaining_steps(void);
void stepper_all_data_signal(void);
void stepper_state_signal(void);
void stepper_set_new_api_state(const uint8_t new_state);

void TC0_IrqHandler(void);
#endif

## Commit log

2011-08-25 initial hardware source commit
    [bricklets.sch, power.sch, powersupply.sch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]
2011-08-25 change voltage epsilon from 200mV to 1000mV
2011-08-26 remove adc tc, periodic conversion now done in bricklib with freerun
2011-08-26 change diode PMEG1020EH -> B0520LW-7-F
    [powersupply.sch, stack.sch, stepper.brd]
2011-09-06 add red led error status code
    [stepper.c]
2011-09-08 use voltage epsilon to switch between external and stack voltage
2011-09-08 compare external voltage for switching between external and stack voltage
2011-09-08 fix bugs in acceleration calculation
    [communication.c, config.h, stepper.c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]
2011-09-13 add java bindings and examples
    [ExampleCallback.java, ExampleConfiguration.java]
2011-10-05 Remove Bindings and IP Connection (these are generated and they change too often) and rename bindings to examples
    [ExampleCallback.java, ExampleConfiguration.java, example_callback.c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]
2012-01-02 add code for voltage divider to allow motor currents below 500mA
2012-02-13 checkin of version 1.1: - remove driver power diodes - add fiducials - add version number in schematics
    [bricklets.sch, power.sch, powersupply.sch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]
2012-02-20 fix wrong capactior value
    [bricklets.sch, power.sch, powersupply.sch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]
2012-03-05 Fix bug with timeouts on windows (through bricklib)
    [config.h]
2012-03-11 Fix bug with ADC calibration readout (through bricklib)
    [config.h]
2012-04-03 add averaging for current measurement
2012-07-24 Stop state machine after disable call, don't drive if max velocity = 0
2012-07-24 Stop completely if max velocity is set to 0 while in drive mode
2012-07-25 Fix callback signature in C/C++ example
    [example_callback.c]
2012-12-11 Avoid g++ warnings about missing casts in C examples
    [example_callback.c]
2013-01-09 Use specific device object for callbacks
2013-01-23 Add missing header to minimum voltage setter
    [communication.h, config.h]
2013-04-11 Add watchdog timer (restart after 16s of "deadlock")
2013-05-28 Fix bug in under voltage callback definition (wrong FID)
    [config.h, stepper.c]
2013-06-27 Use tick_task to detect usb connect/disconnect instead of interrupt (through bricklib)
2014-01-14 perl: Fix warning about unsharing the $stepper variable
2014-02-07 Add Mathematica examples
    [ExampleConfiguration.nb.txt]
2014-04-02 perl: Unify print style
2014-06-12 change voltage divider resistor values for usb detect
    [bricklets.sch, power.sch, powersupply.sch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]
2014-07-01 Add flag to compile with SPI stack DMA protocol (currently deactivated by default)
2014-07-15 java: Replace System.console() usage with an Eclipse compatible pattern
    [ExampleCallback.java, ExampleConfiguration.java]
2014-11-25 Use new SPI protocol
2015-06-24 new stepper prototype, copy from last version, add filtering
    [bricklets.sch, power.sch, powersupply.sch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]
2015-06-24 schematic finished, board added
    [bricklets.sch, power.sch, powersupply.sch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]
2015-06-24 remove old parts, place important components to pcb
    [bricklets.sch, power.sch, powersupply.sch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]
2015-06-30 change step down to ldo, pcb: partially placement
    [bricklets.sch, power.sch, powersupply.sch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]
2015-07-08 placement finished
    [bricklets.sch, power.sch, powersupply.sch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]
2015-07-08 previous commit was uncomplete. parts placement finished
    [bricklets.sch, power.sch, powersupply.sch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]
2015-07-09 changed placement
    [stepper.kicad_pcb]
2015-07-28 partial routing
    [bricklets.sch, power.sch, powersupply.sch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]
2015-08-07 Use full device class name in Python examples
2015-08-12 Fix minor warnings in C/C++ examples
    [example_callback.c, example_configuration.c]
2015-08-25 partially routed
    [bricklets.sch, power.sch, powersupply.sch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]
2015-08-26 change 0402, 0603 footprints to extended versions, fix placement
    [stepper.kicad_pcb]
2015-08-26 fix placement, no drc errors
    [bricklets.sch, stepper.kicad_pcb, stepper.sch]
2015-08-26 add power routing
    [stepper.kicad_pcb]
2015-08-27 more power routing
    [stepper.kicad_pcb]
2015-08-27 routing improved
    [stepper.kicad_pcb, stepper.sch]
2015-08-27 routable, no drc errors
    [stepper.kicad_pcb]
2015-08-27 change power routing
    [bricklets.sch, stepper.kicad_pcb]
2015-08-28 fix power diode position
    [stepper.kicad_pcb]
2015-08-28 fully routed, fine tuning missing
    [stepper.dsn, stepper.kicad_pcb]
2015-08-28 fully routed, logos etc. placed, finished
    [stepper.kicad_pcb]
2015-08-28 ordered version
    [stepper.kicad_pcb]
2015-08-28 add voltage hint
    [stepper.sch]
2015-08-31 fix outer layer signal distance
    [stepper.kicad_pcb]
2015-08-31 fix routing, change name to silent stepper brick
    [stepper.kicad_pcb]
2015-09-14 increase external detection voltage
2015-09-15 move to own repository: silent-stepper-brick
    [bricklets.sch, power.sch, powersupply.sch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]
2015-09-30 Generator based example cleanup
    [ExampleConfiguration.nb.txt]
2016-05-18 c: Add missing device destroy call
    [example_callback.c, example_configuration.c]
2016-07-01 Make the change UID comment more explicit
    [ExampleConfiguration.nb.txt]
2016-12-05 Add ringbuffer and system timer utility as well as co_mcu support files to Makefile (all added through bricklib)
2017-05-12 Add most of the 3d information (tbc)
    Connectors are missing
    [bricklets.sch, power.sch, powersupply.sch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]
2017-06-09 Add missing 3d information
    [stepper.kicad_pcb]
2017-06-16 Add heatsink and new switches to 3d model
    [stepper.kicad_pcb]
2017-06-16 Fix orientation of diodes
    [bricklets.sch, power.sch, powersupply.sch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]
2017-06-16 Add heatsink to 3d model
2018-01-11 Increase version number (message duplication bug fix through bricklib)
    [config.h]
2018-02-20 Cleanup KiCad libraries config
    Ensure LibDir=kicad-libraries and LibName1=tinkerforge.
    Remove special library.
2018-07-25 Add new 3d model
    [stepper.kicad_pcb]
2018-11-07 rust: Accept host names for ip connection, fix naming inconsistencies
    [example_callback.rs, example_configuration.rs]
2019-01-24 mqtt: Add examples.
    [example-configuration.txt]
2019-01-24 mqtt: Fix example header.
    [example-configuration.txt]
2019-01-24 mqtt: Remove executable bit in example permissions.
    [example-configuration.txt]
2019-01-24 mqtt: Minor example fixes.
    [example-configuration.txt]
2019-08-22 c: Adapt to bindings changes
    [example_callback.c]
2020-01-13 examples: mqtt: Remove trailing whitespace.
    [example-configuration.txt]
2020-03-19 examples: Properly stop motor before disabling motor power
    Disabling motor power while motor is still running could cause
    hardware damage.
    [ExampleConfiguration.nb.txt, example-configuration.txt]
2020-04-07 examples: Add missing imports for sleep calls
    [example_callback.rs, example_configuration.rs]
2020-04-07 examples: rust: Always block when calling bindings functions.
    [example_configuration.rs]
2020-04-07 examples: rust: Block when calling bindings functions.
    [example_callback.rs]
2021-10-25 Update KiCad link
    https://www.kicad.org/blog/2021/10/Avoid-links-to-former-kicad-domain/
2024-02-21 examples/rust: Fix random number generation.
    [example_callback.rs]
